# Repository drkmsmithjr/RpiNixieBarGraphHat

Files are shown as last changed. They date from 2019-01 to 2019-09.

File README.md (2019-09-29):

# Nixie Bar Graph Hat for Raspberry Pi Zero (updated to Part 2)
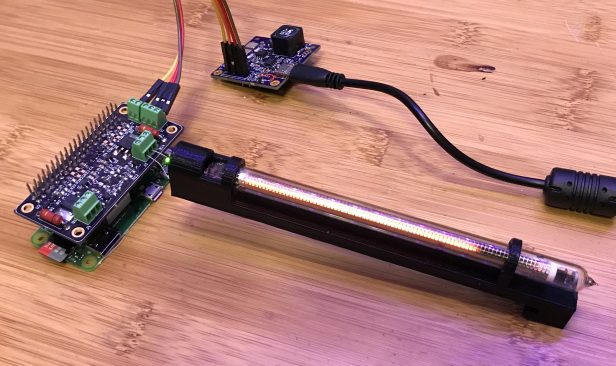
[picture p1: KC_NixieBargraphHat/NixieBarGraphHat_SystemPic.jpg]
JPG of the NixieBarGraphHat System, HAT + raspberry pi + power supply


This project as described in [www.surfncircuits.com](https://wp.me/p85ddV-HQ) came about because I needed a retro looking linear meter for my espresso maker water tank. I’m always running out of water in my espresso maker, and a cool display letting me know how much water is left and to let me know when to fill it up is definitely needed. In this project, I’ll create a HAT for the Raspberry Pi that can drive two IN-9 or IN-13 linear Nixie tubes. While I’m using this HAT as a single water meter display, this same linear display would be great for showing temperature, bar graphs, audio VU meters, even surf heights by days of the week. The [Nixie Tube Power Supply](https://wp.me/p85ddV-Ck), designed in an earlier blog will work perfectly to drive up to four of the IN-13 Nixie tubes or one IN-9 Nixie tube.

This github repository contains the Kicad Schematic, Layout, and Python Library for a PCB Hat that works with the Rasperry Pi Zero, and B+ along with the [Nixie Tube Power Supply](https://wp.me/p85ddV-Ck).  

SVG of the Schematic

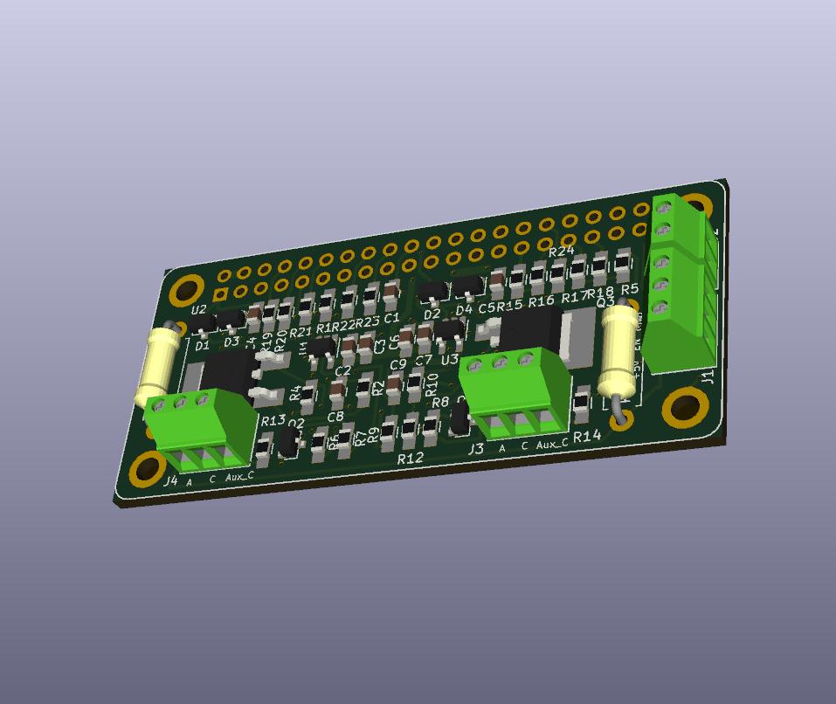
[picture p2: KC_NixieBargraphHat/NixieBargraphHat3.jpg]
SVG of the 3D Image


__KC_NixieBarGraphHat__:  Kicad schematic, PCB layout, [BOM](https://github.com/drkmsmithjr/RpiNixieBarGraphHat/blob/master/KC_NixieBargraphHat/NixieBargraphHat.ods) of the HAT.  The footprint is designed to mounted to the top of the Raspberry Pin zero and B+.   The board is orderable at 

__PythonRpiIN9Nixie__:  The Python Library that can control and the Nixie Bar Graph Hat.   Please see the README file in this submodule and the Blog Entry at [surfncircuits](http://www.surfncircuits.com) for details on how to install the library and how it runs.  

__Datasheeets__: Datasheets for the different components on the pCB.   Many of the datasheets are also linked directly in the Kicad schematic to the Digikey (TM) datasheet.    

See other reference blogs entry at  www.surfncircuits.com:
  * [KiCad Power Tools Help Shrink The Nixie Tube Power Supply (part 3)](https://wp.me/p85ddV-Ck)

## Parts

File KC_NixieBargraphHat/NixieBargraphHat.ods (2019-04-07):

Source: | /home/mark/Dropbox/personal/SurfnCircuits/NixieBarGraphHat/KC_NixieBargraphHat/NixieBargraphHat.sch
Date: | Sat 06 Apr 2019 09:19:30 PM PDT
Tool: | Eeschema 4.0.7-e2-6376~61~ubuntu18.04.1
Generator: | /usr/lib/kicad/plugins/bom_csv_grouped_by_value.py
Component Count: | 50
Individual Components:
Item | Qty | Reference(s) | Value | LibPart | Footprint | Datasheet | MPN
 |  | C1 | 3.3nF | device:C | Capacitors_SMD:C_0805_HandSoldering | https://www.digikey.com/product-detail/en/kemet/C0805C332KDRACAUTO/399-16654-1-ND/8110020 | C0805C332KDRACAUTO
 |  | C2 | 0.1uF | device:C | Capacitors_SMD:C_0805_HandSoldering | https://www.digikey.com/product-detail/en/kemet/C0805C104K3RACTU/399-1168-2-ND/411167 | C0805C104K3RACTU
 |  | C3 | 1uF | device:C | Capacitors_SMD:C_0805_HandSoldering | https://www.digikey.com/product-detail/en/samsung-electro-mechanics/CL21F105ZBFNNNE/1276-3010-2-ND/3888668 | CL21F105ZBFNNNE
 |  | C4 | 1uF | device:C | Capacitors_SMD:C_0805_HandSoldering | https://www.digikey.com/product-detail/en/samsung-electro-mechanics/CL21F105ZBFNNNE/1276-3010-2-ND/3888668 | CL21F105ZBFNNNE
 |  | C5 | 3.3nF | device:C | Capacitors_SMD:C_0805_HandSoldering | https://www.digikey.com/product-detail/en/kemet/C0805C332KDRACAUTO/399-16654-1-ND/8110020 | C0805C332KDRACAUTO
 |  | C6 | 0.1uF | device:C | Capacitors_SMD:C_0805_HandSoldering | https://www.digikey.com/product-detail/en/kemet/C0805C104K3RACTU/399-1168-2-ND/411167 | C0805C104K3RACTU
 |  | C7 | 1uF | device:C | Capacitors_SMD:C_0805_HandSoldering | https://www.digikey.com/product-detail/en/samsung-electro-mechanics/CL21F105ZBFNNNE/1276-3010-2-ND/3888668 | CL21F105ZBFNNNE
 |  | C8 | 1nF | device:C | Capacitors_SMD:C_0805_HandSoldering | https://www.digikey.com/product-detail/en/kemet/C0805C102J5HACAUTO/399-16591-1-ND/7943643 | C0805C102J5HACAUTO
 |  | C9 | 1nF | device:C | Capacitors_SMD:C_0805_HandSoldering | https://www.digikey.com/product-detail/en/kemet/C0805C102J5HACAUTO/399-16591-1-ND/7943643 | C0805C102J5HACAUTO
 |  | D1 | BAV99 | device:D_x2_Serial_AKC | TO_SOT_Packages_SMD:SOT-23 | https://www.digikey.com/product-detail/en/nexperia-usa-inc/BAV99235/1727-4311-1-ND/2209921 | BAV99,235
 |  | D2 | BAV99 | device:D_x2_Serial_AKC | TO_SOT_Packages_SMD:SOT-23 | https://www.digikey.com/product-detail/en/nexperia-usa-inc/BAV99235/1727-4311-1-ND/2209921 | BAV99,235
 |  | D3 | BAV99 | device:D_x2_Serial_AKC | TO_SOT_Packages_SMD:SOT-23 | https://www.digikey.com/product-detail/en/nexperia-usa-inc/BAV99235/1727-4311-1-ND/2209921 | BAV99,235
 |  | D4 | BAV99 | device:D_x2_Serial_AKC | TO_SOT_Packages_SMD:SOT-23 | https://www.digikey.com/product-detail/en/nexperia-usa-inc/BAV99235/1727-4311-1-ND/2209921 | BAV99,235
 |  | J1 | Screw_Terminal_1x03 | NixieSupply5vto170vDCMBoostMini-cache:Screw_Terminal_1x03 | TerminalBlock_Phoenix:TerminalBlock_Phoenix_MPT-2.54mm_3pol | https://www.digikey.com/product-detail/en/phoenix-contact/1725669/277-1274-ND/267463 | 1725669
 |  | J2 | Screw_Terminal_1x02 | NixieSupply5vto170vDCMBoostMini-cache:Screw_Terminal_1x02 | TerminalBlock_Phoenix:TerminalBlock_Phoenix_MPT-2.54mm_2pol | https://www.digikey.com/product-detail/en/phoenix-contact/1725656/277-1273-ND/267462 | 1725656
 |  | J3 | Screw_Terminal_1x03 | NixieSupply5vto170vDCMBoostMini-cache:Screw_Terminal_1x03 | TerminalBlock_Phoenix:TerminalBlock_Phoenix_MPT-2.54mm_3pol | https://www.digikey.com/product-detail/en/phoenix-contact/1725669/277-1274-ND/267463 | 1725669
 |  | J4 | Screw_Terminal_1x03 | NixieSupply5vto170vDCMBoostMini-cache:Screw_Terminal_1x03 | TerminalBlock_Phoenix:TerminalBlock_Phoenix_MPT-2.54mm_3pol | https://www.digikey.com/product-detail/en/phoenix-contact/1725669/277-1274-ND/267463 | 1725669
 |  | N1 | IN-9 | nixies-us:IN-9 | nixies-us_IN-9
 |  | N2 | IN-9 | nixies-us:IN-9 | nixies-us_IN-9
 |  | Q1 | FDD7N25LZTM | transistors:BSP129 | TO_SOT_Packages_SMD:TO-252-2Lead | https://www.digikey.com/product-detail/en/on-semiconductor/FDD7N25LZTM/FDD7N25LZTMCT-ND/3908038 | FDD7N25LZTM
 |  | Q2 | 2N7002 | transistors:2N7002 | TO_SOT_Packages_SMD:SOT-23 | https://www.digikey.com/product-detail/en/micro-commercial-co/2N7002-TP/2N7002-TPMSTR-ND/1959296 | 2N7002-TP
 |  | Q3 | FDD7N25LZTM | transistors:BSP129 | TO_SOT_Packages_SMD:TO-252-2Lead | https://www.digikey.com/product-detail/en/on-semiconductor/FDD7N25LZTM/FDD7N25LZTMCT-ND/3908038 | FDD7N25LZTM
 |  | Q4 | 2N7002 | transistors:2N7002 | TO_SOT_Packages_SMD:SOT-23 | https://www.digikey.com/product-detail/en/micro-commercial-co/2N7002-TP/2N7002-TPMSTR-ND/1959296 | 2N7002-TP
 |  | R1 | 1k | device:R | Resistors_SMD:R_0805_HandSoldering | https://www.digikey.com/product-detail/en/yageo/RC0805FR-071KL/311-1.00KCRCT-ND/730391 | RC0805FR-071KL
 |  | R2 | 1k | device:R | Resistors_SMD:R_0805_HandSoldering | https://www.digikey.com/product-detail/en/yageo/RC0805FR-071KL/311-1.00KCRCT-ND/730391 | RC0805FR-078K2L
 |  | R3 | 1k 2W | device:R | Resistors_THT:R_Axial_DIN0411_L9.9mm_D3.6mm_P12.70mm_Horizontal | https://www.digikey.com/product-detail/en/vishay-bc-components/PR02000201001JR500/PPC1.0KW-2TR-ND/596130 | PR02000201001JR500
 |  | R4 | 133 | device:R | Resistors_SMD:R_0805_HandSoldering | https://www.digikey.com/product-detail/en/yageo/RC0805FR-07133RL/311-133CRCT-ND/730538 | RC0805FR-07133RL
 |  | R5 | 1k | device:R | Resistors_SMD:R_0805_HandSoldering | https://www.digikey.com/product-detail/en/yageo/RC0805FR-071KL/311-1.00KCRCT-ND/730391 | RC0805FR-071KL
 |  | R6 | 1k | device:R | Resistors_SMD:R_0805_HandSoldering | https://www.digikey.com/product-detail/en/yageo/RC0805FR-071KL/311-1.00KCRCT-ND/730391 | RC0805FR-071KL
 |  | R7 | 1k | device:R | Resistors_SMD:R_0805_HandSoldering | https://www.digikey.com/product-detail/en/yageo/RC0805FR-071KL/311-1.00KCRCT-ND/730391 | RC0805FR-071KL
 |  | R8 | 1k | device:R | Resistors_SMD:R_0805_HandSoldering | https://www.digikey.com/product-detail/en/yageo/RC0805FR-071KL/311-1.00KCRCT-ND/730391 | RC0805FR-071KL
 |  | R9 | 1k | device:R | Resistors_SMD:R_0805_HandSoldering | https://www.digikey.com/product-detail/en/yageo/RC0805FR-071KL/311-1.00KCRCT-ND/730391 | RC0805FR-078K2L
 |  | R10 | 1k | device:R | Resistors_SMD:R_0805_HandSoldering | https://www.digikey.com/product-detail/en/yageo/RC0805FR-071KL/311-1.00KCRCT-ND/730391 | RC0805FR-071KL
 |  | R11 | 1k 2W | device:R | Resistors_THT:R_Axial_DIN0411_L9.9mm_D3.6mm_P12.70mm_Horizontal | https://www.digikey.com/product-detail/en/vishay-bc-components/PR02000201001JR500/PPC1.0KW-2TR-ND/596130 | PR02000201001JR500
 |  | R12 | 133 | device:R | Resistors_SMD:R_0805_HandSoldering | https://www.digikey.com/product-detail/en/yageo/RC0805FR-07133RL/311-133CRCT-ND/730538 | RC0805FR-07133RL
 |  | R13 | 220k | device:R | Resistors_SMD:R_0805_HandSoldering | https://www.digikey.com/product-detail/en/te-connectivity-passive-product/CRGCQ0805F220K/A129777CT-ND/8577609 | CRGCQ0805F220K
 |  | R14 | 220k | device:R | Resistors_SMD:R_0805_HandSoldering | https://www.digikey.com/product-detail/en/te-connectivity-passive-product/CRGCQ0805F220K/A129777CT-ND/8577609 | CRGCQ0805F220K
 |  | R15 | NU | device:R | Resistors_SMD:R_0805_HandSoldering
 |  | R16 | 0 | device:R | Resistors_SMD:R_0805_HandSoldering
 |  | R17 | 0 | device:R | Resistors_SMD:R_0805_HandSoldering
 |  | R18 | NU | device:R | Resistors_SMD:R_0805_HandSoldering
 |  | R19 | 0 | device:R | Resistors_SMD:R_0805_HandSoldering
 |  | R20 | 1k | device:R | Resistors_SMD:R_0805_HandSoldering | https://www.digikey.com/product-detail/en/yageo/RC0805FR-071KL/311-1.00KCRCT-ND/730391
 |  | R21 | 0 | device:R | Resistors_SMD:R_0805_HandSoldering
 |  | R22 | NU | device:R | Resistors_SMD:R_0805_HandSoldering
 |  | R23 | NU | device:R | Resistors_SMD:R_0805_HandSoldering
 |  | R24 | NU | device:R | Resistors_SMD:R_0805_HandSoldering
 |  | U1 | MCP6411 | linear:MCP6001 | TO_SOT_Packages_SMD:SOT-23-5_HandSoldering | http://ww1.microchip.com/downloads/en/DeviceDoc/20005791B.pdf | MCP6411T-E/OT
 |  | U2 | Raspberry_PI_Zero_Header | ETAclock-cache:Raspberry_PI_Zero_Hat | etaclock:Raspberry_Pi_Zero_40pins
 |  | U3 | MCP6411 | linear:MCP6001 | TO_SOT_Packages_SMD:SOT-23-5_HandSoldering | http://ww1.microchip.com/downloads/en/DeviceDoc/20005791B.pdf | MCP6411T-E/OT
Collated Components:
Item | Qty | Reference(s) | Value | LibPart | Footprint | Datasheet | MPN
1 | 2 | C1, C5 | 3.3nF | device:C | Capacitors_SMD:C_0805_HandSoldering | https://www.digikey.com/product-detail/en/kemet/C0805C332KDRACAUTO/399-16654-1-ND/8110020 | C0805C332KDRACAUTO
2 | 2 | C2, C6 | 0.1uF | device:C | Capacitors_SMD:C_0805_HandSoldering | https://www.digikey.com/product-detail/en/kemet/C0805C104K3RACTU/399-1168-2-ND/411167 | C0805C104K3RACTU
3 | 3 | C3, C4, C7 | 1uF | device:C | Capacitors_SMD:C_0805_HandSoldering | https://www.digikey.com/product-detail/en/samsung-electro-mechanics/CL21F105ZBFNNNE/1276-3010-2-ND/3888668 | CL21F105ZBFNNNE
4 | 2 | C8, C9 | 1nF | device:C | Capacitors_SMD:C_0805_HandSoldering | https://www.digikey.com/product-detail/en/kemet/C0805C102J5HACAUTO/399-16591-1-ND/7943643 | C0805C102J5HACAUTO
5 | 4 | D1, D2, D3, D4 | BAV99 | device:D_x2_Serial_AKC | TO_SOT_Packages_SMD:SOT-23 | https://www.digikey.com/product-detail/en/nexperia-usa-inc/BAV99235/1727-4311-1-ND/2209921 | BAV99,235
6 | 3 | J1, J3, J4 | Screw_Terminal_1x03 | NixieSupply5vto170vDCMBoostMini-cache:Screw_Terminal_1x03 | TerminalBlock_Phoenix:TerminalBlock_Phoenix_MPT-2.54mm_3pol | https://www.digikey.com/product-detail/en/phoenix-contact/1725669/277-1274-ND/267463 | 1725669
7 | 1 | J2 | Screw_Terminal_1x02 | NixieSupply5vto170vDCMBoostMini-cache:Screw_Terminal_1x02 | TerminalBlock_Phoenix:TerminalBlock_Phoenix_MPT-2.54mm_2pol | https://www.digikey.com/product-detail/en/phoenix-contact/1725656/277-1273-ND/267462 | 1725656
8 | 2 | N1, N2 | IN-9 | nixies-us:IN-9 | nixies-us_IN-9
9 | 2 | Q1, Q3 | FDD7N25LZTM | transistors:BSP129 | TO_SOT_Packages_SMD:TO-252-2Lead | https://www.digikey.com/product-detail/en/on-semiconductor/FDD7N25LZTM/FDD7N25LZTMCT-ND/3908038 | FDD7N25LZTM
10 | 2 | Q2, Q4 | 2N7002 | transistors:2N7002 | TO_SOT_Packages_SMD:SOT-23 | https://www.digikey.com/product-detail/en/micro-commercial-co/2N7002-TP/2N7002-TPMSTR-ND/1959296 | 2N7002-TP
11 | 9 | R1, R2, R5, R6, R7, R8, R9, R10, R20 | 1k | device:R | Resistors_SMD:R_0805_HandSoldering | https://www.digikey.com/product-detail/en/yageo/RC0805FR-071KL/311-1.00KCRCT-ND/730391 | RC0805FR-071KL
12 | 2 | R3, R11 | 1k 2W | device:R | Resistors_THT:R_Axial_DIN0411_L9.9mm_D3.6mm_P12.70mm_Horizontal | https://www.digikey.com/product-detail/en/vishay-bc-components/PR02000201001JR500/PPC1.0KW-2TR-ND/596130 | PR02000201001JR500
13 | 2 | R4, R12 | 133 | device:R | Resistors_SMD:R_0805_HandSoldering | https://www.digikey.com/product-detail/en/yageo/RC0805FR-07133RL/311-133CRCT-ND/730538 | RC0805FR-07133RL
14 | 2 | R13, R14 | 220k | device:R | Resistors_SMD:R_0805_HandSoldering | https://www.digikey.com/product-detail/en/te-connectivity-passive-product/CRGCQ0805F220K/A129777CT-ND/8577609 | CRGCQ0805F220K
15 | 5 | R15, R18, R22, R23, R24 | NU | device:R | Resistors_SMD:R_0805_HandSoldering
16 | 4 | R16, R17, R19, R21 | 0 | device:R | Resistors_SMD:R_0805_HandSoldering
17 | 2 | U1, U3 | MCP6411 | linear:MCP6001 | TO_SOT_Packages_SMD:SOT-23-5_HandSoldering | http://ww1.microchip.com/downloads/en/DeviceDoc/20005791B.pdf | MCP6411T-E/OT
18 | 1 | U2 | Raspberry_PI_Zero_Header | ETAclock-cache:Raspberry_PI_Zero_Hat | etaclock:Raspberry_Pi_Zero_40pins

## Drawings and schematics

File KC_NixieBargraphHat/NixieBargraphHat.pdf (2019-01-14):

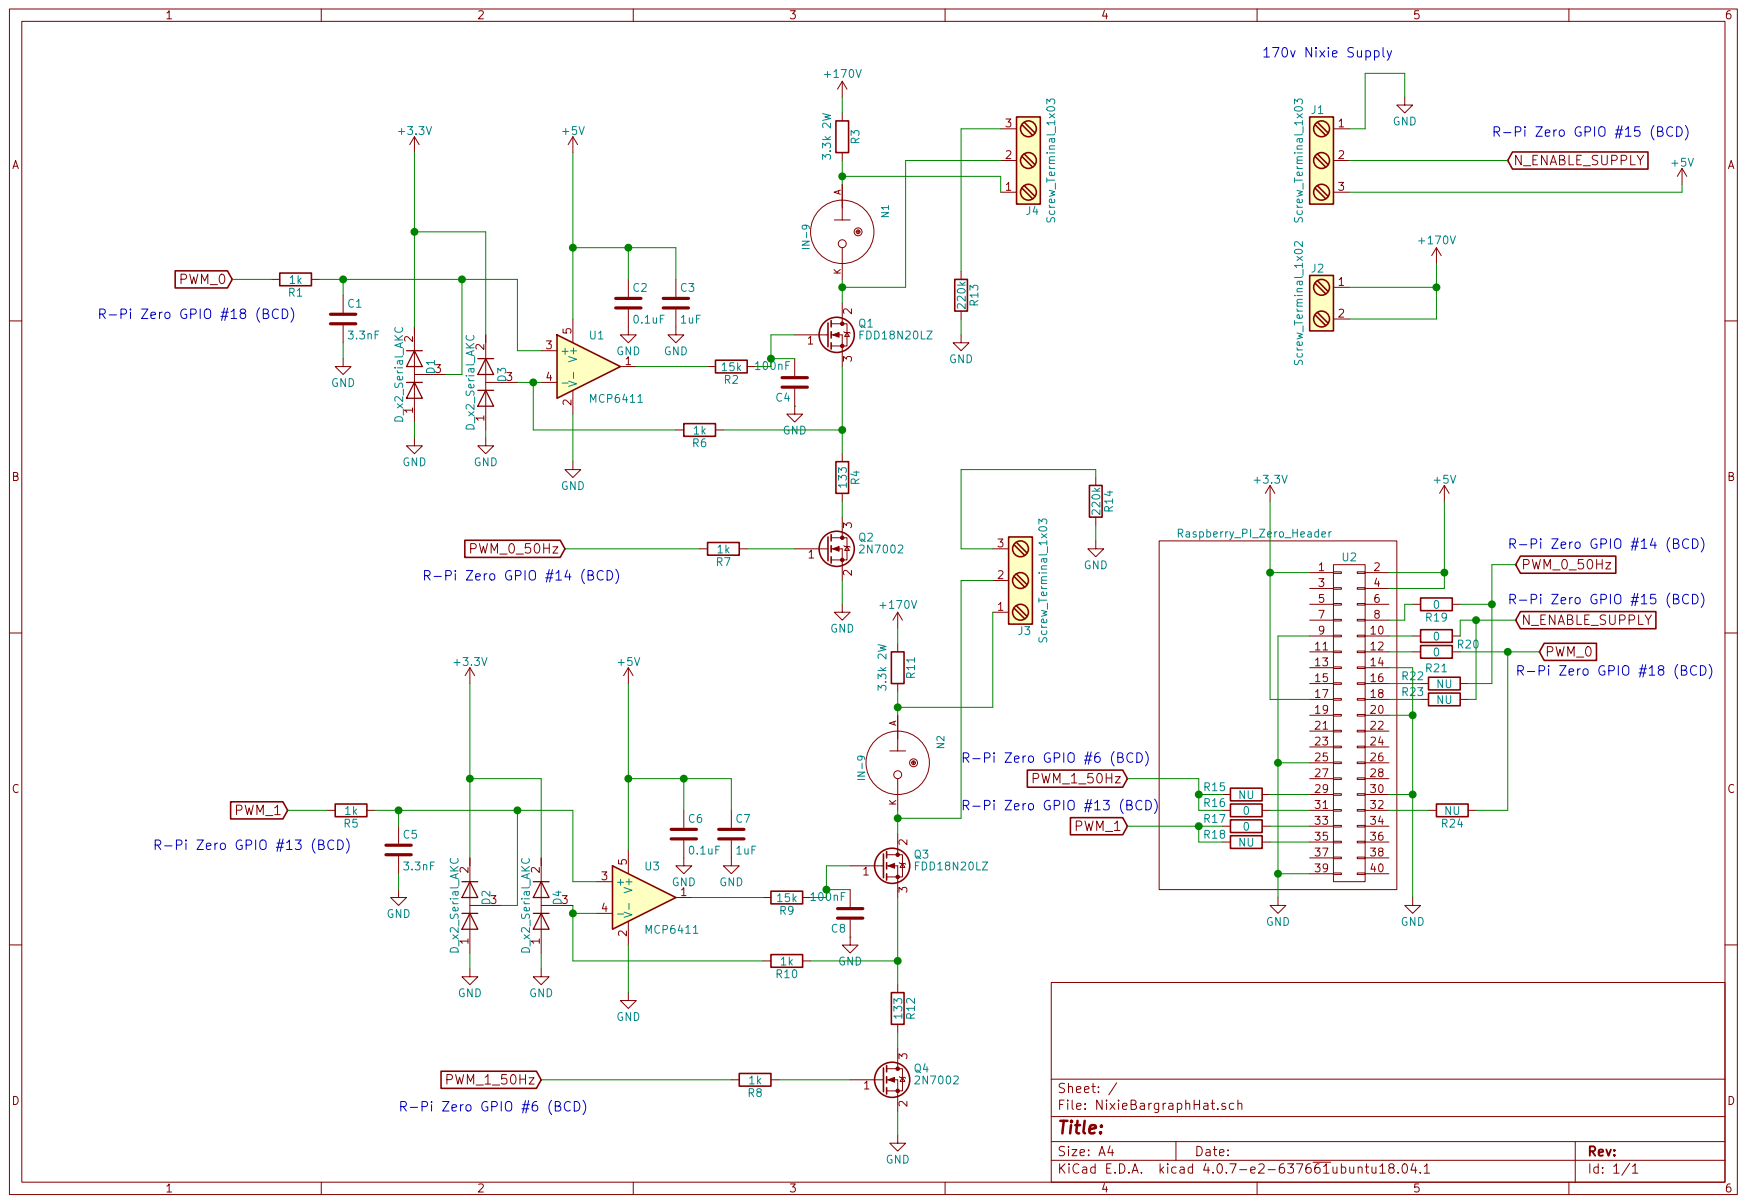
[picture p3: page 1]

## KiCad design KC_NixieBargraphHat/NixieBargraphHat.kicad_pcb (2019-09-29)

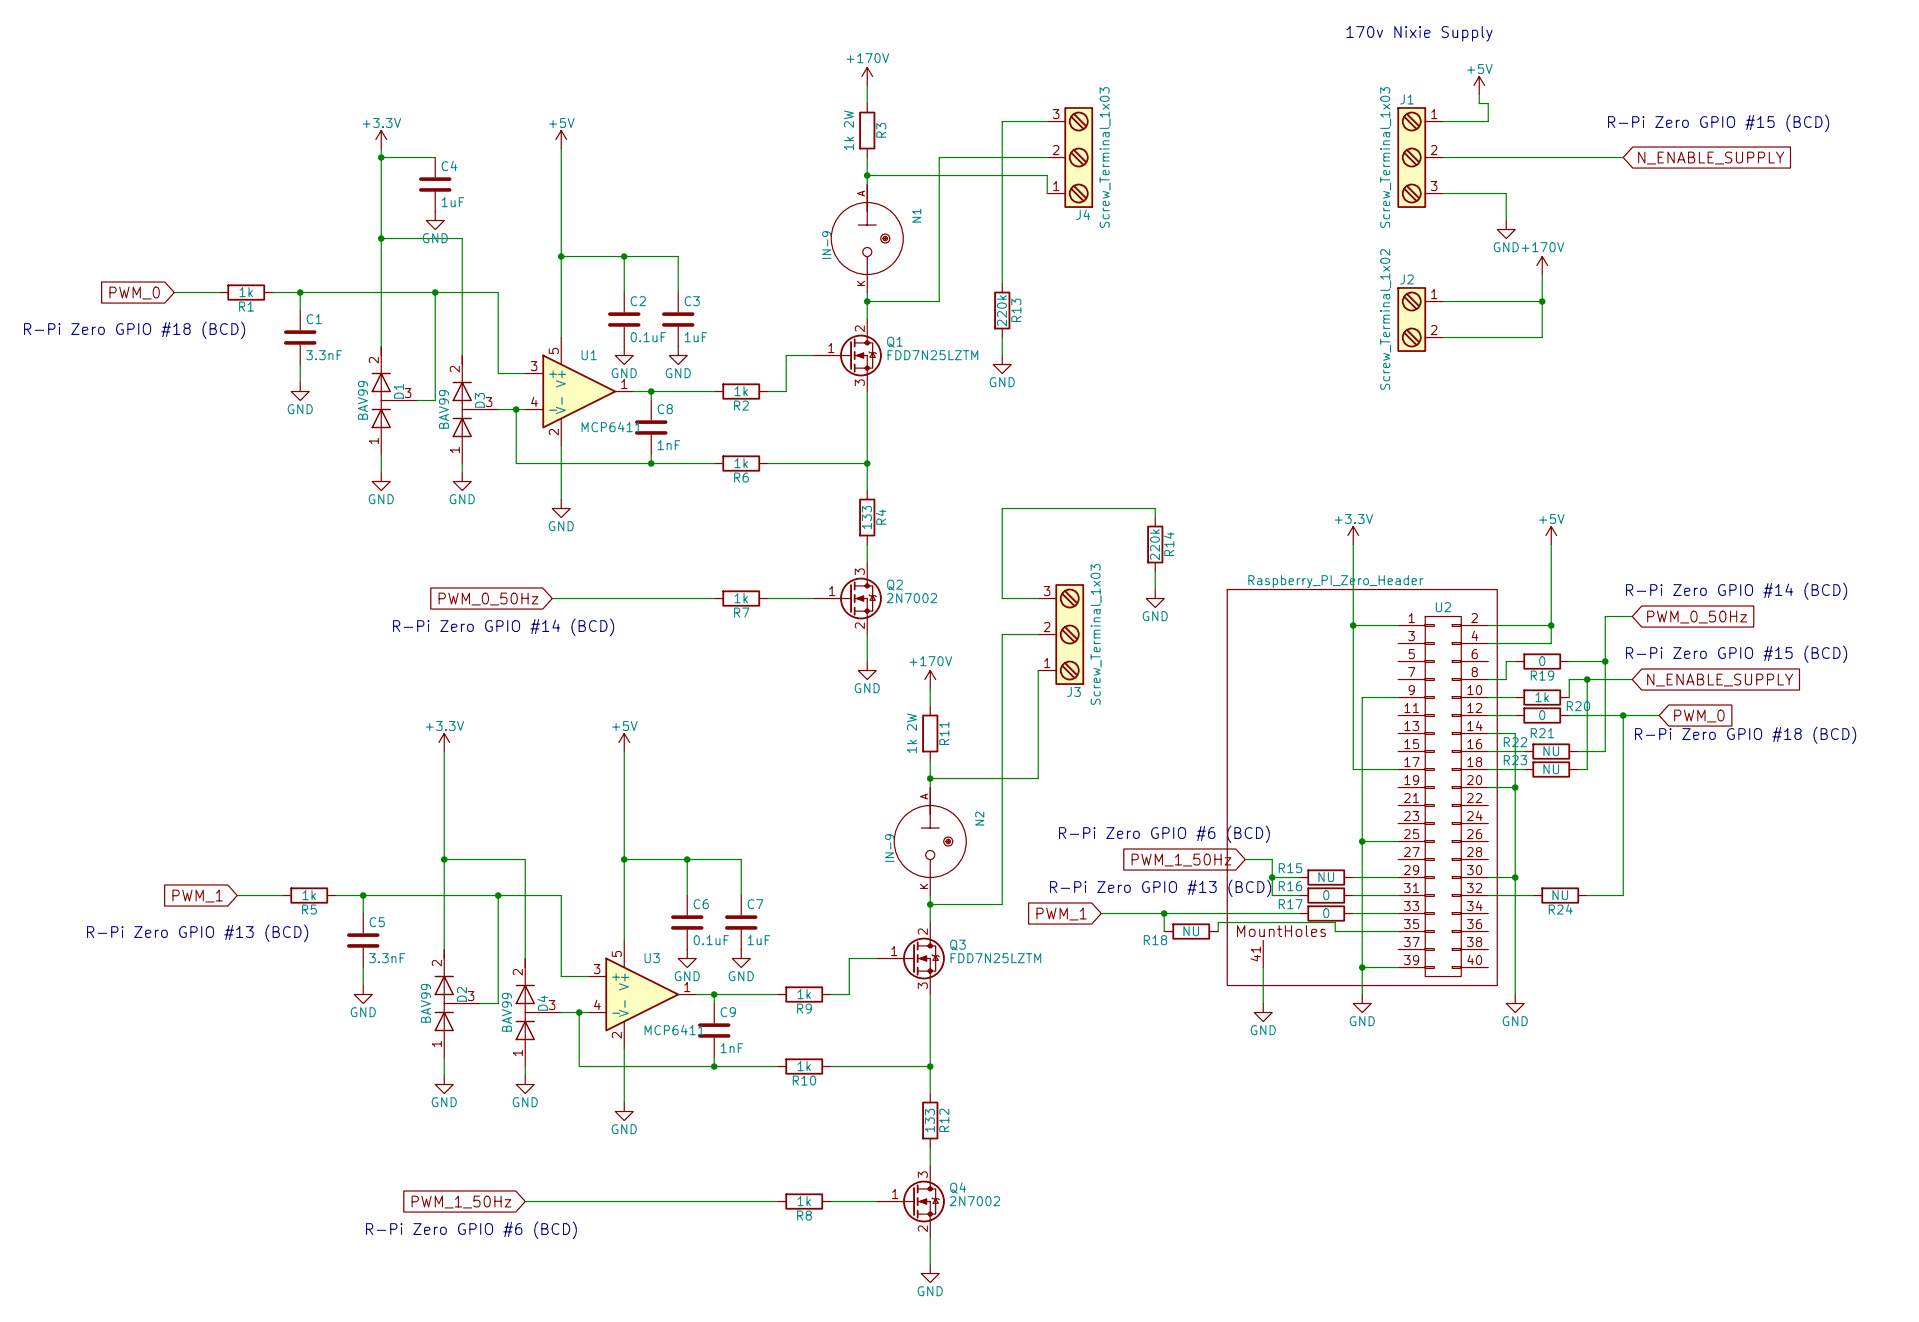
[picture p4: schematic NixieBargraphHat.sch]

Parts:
C1, C5: 3.3nF; C_0805_HandSoldering; MPN C0805C332KDRACAUTO
C2, C6: 0.1uF; C_0805_HandSoldering; MPN C0805C104K3RACTU
C3, C4, C7: 1uF; C_0805_HandSoldering; MPN CL21F105ZBFNNNE
C8, C9: 1nF; C_0805_HandSoldering; MPN C0805C102J5HACAUTO
D1, D2, D3, D4: BAV99; SOT-23; MPN BAV99,235
J1, J3, J4: Screw_Terminal_1x03; TerminalBlock_Phoenix_MPT-2.54mm_3pol; MPN 1725669
J2: Screw_Terminal_1x02; TerminalBlock_Phoenix_MPT-2.54mm_2pol; MPN 1725656
N1, N2: IN-9
Q1, Q3: FDD7N25LZTM; TO-252-2Lead; MPN FDD7N25LZTM
Q2, Q4: 2N7002; SOT-23; MPN 2N7002-TP
R1, R5, R6, R7, R8, R10: 1k; R_0805_HandSoldering; MPN RC0805FR-071KL
R2, R9: 1k; R_0805_HandSoldering; MPN RC0805FR-078K2L
R3, R11: 1k 2W; R_Axial_DIN0411_L9.9mm_D3.6mm_P12.70mm_Horizontal; MPN PR02000201001JR500
R4, R12: 133; R_0805_HandSoldering; MPN RC0805FR-07133RL
R13, R14: 220k; R_0805_HandSoldering; MPN CRGCQ0805F220K
R15, R18, R22, R23, R24: NU; R_0805_HandSoldering
R16, R17, R19, R21: 0; R_0805_HandSoldering
R20: 1k; R_0805_HandSoldering
U1, U3: MCP6411; SOT-23-5_HandSoldering; MPN MCP6411T-E/OT
U2: Raspberry_PI_Zero_Header; Raspberry_Pi_Zero_40pins

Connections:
+3V3: C4.1, D1.2 (K), D2.2 (K), D3.2 (K), D4.2 (K), U2.1, U2.17
+5V: C2.1, C3.1, C6.1, C7.1, J1.1, U1.5 (V+), U2.2, U2.4, U3.5 (V+)
+170V: J2.1, J2.2, R3.1, R11.1
GND: C1.2, C2.2, C3.2, C4.2, C5.2, C6.2, C7.2, D1.1 (A), D2.1 (A), D3.1 (A), D4.1 (A), J1.3, Q2.2 (S), Q4.2 (S), R13.2, R14.2, U1.2 (V-), U2.9, U2.14, U2.20, U2.25, U2.30, U2.39, U2.41 (MountHoles), U3.2 (V-)
N_ENABLE_SUPPLY: J1.2, R20.1, R23.1
unnamed: C1.1, D1.3 (common), R1.1, U1.3 (+)
unnamed: C5.1, D2.3 (common), R5.1, U3.3 (+)
unnamed: C8.1, R2.2, U1.1
unnamed: C8.2, D3.3 (common), R6.2, U1.4 (-)
unnamed: C9.1, R9.2, U3.1
unnamed: C9.2, D4.3 (common), R10.2, U3.4 (-)
unnamed: J3.1, N2.A, R11.2
unnamed: J3.2, N2.K, Q3.2 (D)
unnamed: J3.3, R14.1
unnamed: J4.1, N1.A, R3.2
unnamed: J4.2, N1.K, Q1.2 (D)
unnamed: J4.3, R13.1
unnamed: Q1.1 (G), R2.1
unnamed: Q1.3 (S), R4.1, R6.1
unnamed: Q2.1 (G), R7.1
unnamed: Q2.3 (D), R4.2
unnamed: Q3.1 (G), R9.1
unnamed: Q3.3 (S), R10.1, R12.1
unnamed: Q4.1 (G), R8.1
unnamed: Q4.3 (D), R12.2
unnamed: R15.1, U2.29
unnamed: R16.1, U2.31
unnamed: R17.1, U2.33
unnamed: R18.1, U2.35
unnamed: R19.2, U2.8
unnamed: R20.2, U2.10
unnamed: R21.2, U2.12
unnamed: R22.2, U2.16
unnamed: R23.2, U2.18
unnamed: R24.2, U2.32
PWM_0: R1.2, R21.1, R24.1
PWM_0_50Hz: R7.2, R19.1, R22.1
PWM_1: R5.2, R17.2, R18.2
PWM_1_50Hz: R8.2, R15.2, R16.2

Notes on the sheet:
R-Pi Zero GPIO #18 (BCD)
R-Pi Zero GPIO #14 (BCD)
R-Pi Zero GPIO #15 (BCD)
170v Nixie Supply
R-Pi Zero GPIO #13 (BCD)
R-Pi Zero GPIO #6 (BCD)

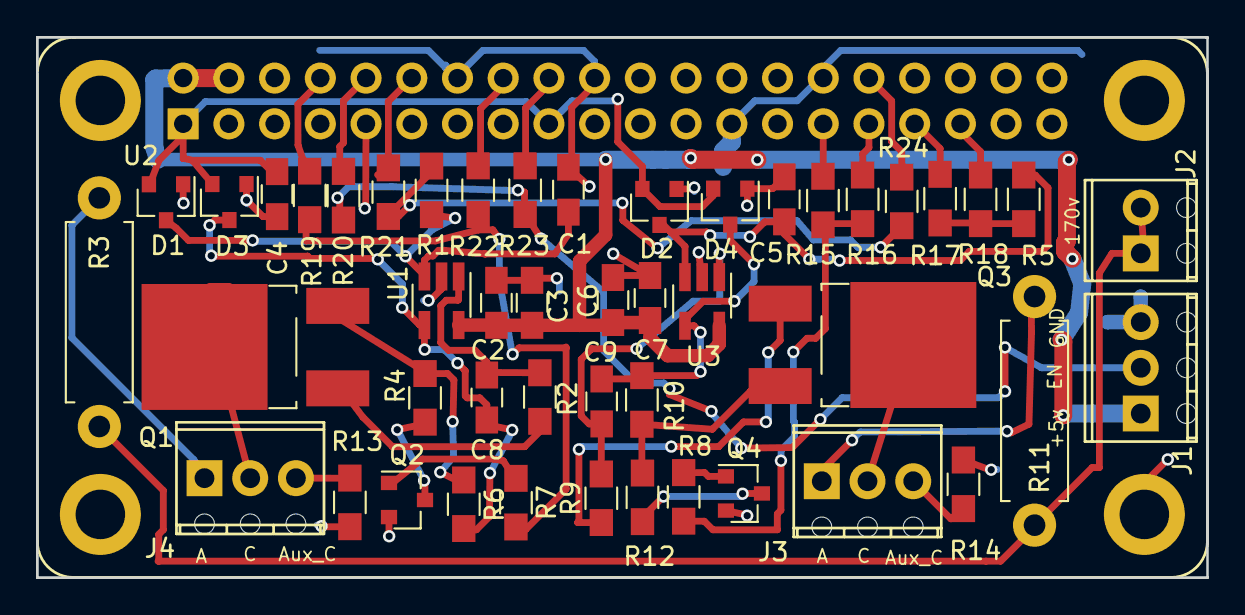
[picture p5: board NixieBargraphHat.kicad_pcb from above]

Board: 2 copper layers, 65.0 x 30.0 mm, 48 parts (0 on the bottom side), 39 nets.

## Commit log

2019-01-07 Initial entry of the IN-9 Hat for the Raspbarry Pi Zero
    [NixieBargraphHat.kicad_pcb, NixieBargraphHat.sch]
2019-01-13 Added connectors for the power supply and the Raspberry Pi header
    [NixieBargraphHat.sch]
2019-01-13 removed image
    [NixieBargraphHat.sch]
2019-01-13 ploted the schematic and added a readme file along with a license file
2019-01-14 Adjusted the schematic to have two channels for the Left and Right Nixie. Also adjusted the PWM to have hardware PWM for the cathod signals, but the low frequency dimming will be done with the 50 Hz 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
    [NixieBargraphHat.sch]
2019-01-17 updated the schematic to include a feedback for op-amp to avoid oscillation
    [NixieBargraphHat.sch]
2019-01-26 updated the schematic with dual solution for left and right channels
    [NixieBargraphHat.sch]
2019-01-26 updated with new README file to reference the new schematic
2019-02-16 updated layout files.
    [NixieBargraphHat.kicad_pcb, NixieBargraphHat.ods, NixieBargraphHat.sch]
2019-02-16 added gerber files
    [NixieBargraphHat.kicad_pcb]
2019-02-18 Updated the BOM to a different FET that is in stock 250v
    [NixieBargraphHat.ods, NixieBargraphHat.sch]
2019-02-18 added datasheet of new FET
2019-03-18 adjusted the gate resistor for increased bandwidth
    [NixieBargraphHat.ods, NixieBargraphHat.sch]
2019-04-07 Updated the follwoing changes: 1. Adjusted the gate resistor BOM to include a 1kohm resistor to gate of mosfet 2. updated silk screen to add labels for each of the Nixie tube and power supply connect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
    [NixieBargraphHat-B.Cu.gbl, NixieBargraphHat-B.Mask.gbs, NixieBargraphHat-B.SilkS.gbo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]
2019-04-07 updated the BOM to add the changes R2 and R9
    [NixieBargraphHat.ods]
2019-04-07 update BOM to add 1k to enable pin
    [NixieBargraphHat.ods, NixieBargraphHat.sch]
2019-09-29 Added all the changes for Part 2 of the Hat. UPdated silksceen, reduced R2 and R9, new gerbers (Part 2). The original gerbers were saved.
    [NixieBargraphHat-B.Cu.gbl, NixieBargraphHat-B.Mask.gbs, NixieBargraphHat-B.SilkS.gbo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]
2019-09-29 added new schematic picture
2019-09-29 moved the schematic and 3d images files
2019-09-29 Update README.md
    fixed the file link for the schematic
2019-09-29 updated the schematic file
2019-09-29 updated the schematic
    [NixieBargraphHat.sch]
2019-09-29 Update README.md
    Added link to the BOM open libre file format.
